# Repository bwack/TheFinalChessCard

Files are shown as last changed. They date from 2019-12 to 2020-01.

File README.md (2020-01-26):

# TheFinalChessCard Replica

TheFinalChessCard for C64/C128, replicated using SprintLayout. Here are the sprint and gerber files.

The scanned images are from the World of Jani blog article about this card. See also the forum64.de threads.
- http://blog.worldofjani.com/?p=3460
- https://www.forum64.de/index.php?thread/73757-the-final-chesscard/

## preview images from SprintLayout

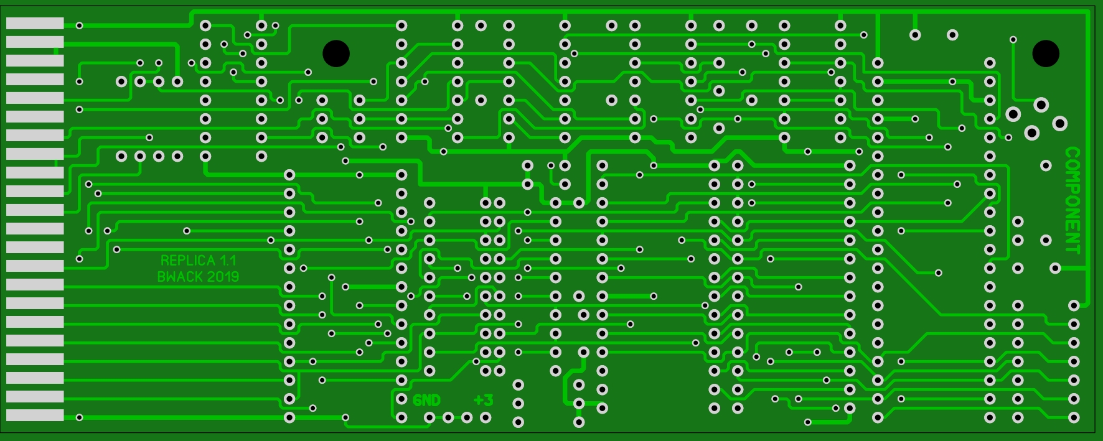
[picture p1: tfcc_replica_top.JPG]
replica top

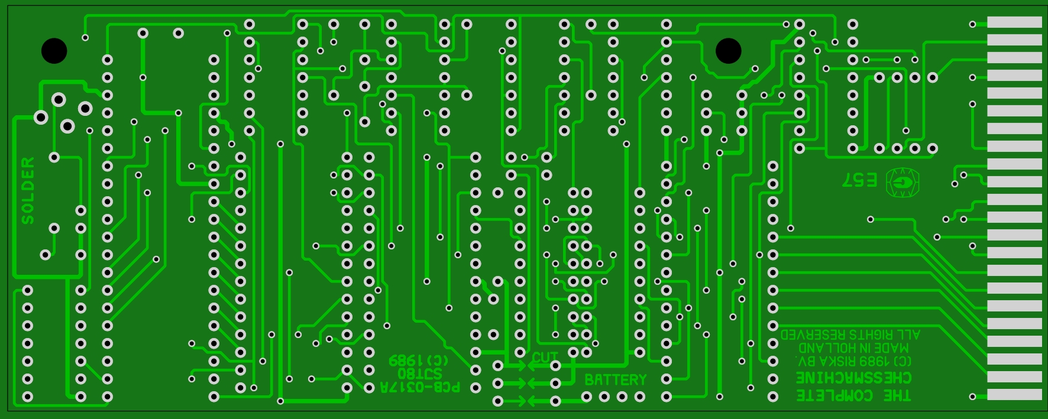
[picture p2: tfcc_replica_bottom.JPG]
replica bottom


# The Replica 1.0 prototype

The PCB Rev 1.0 has been [prototyped by Amon_RA on twitter](https://twitter.com/Amon_RA/status/1220659582181224448 "The tweets"). Thank you so much! Here are two images from his setup:

Image 1            |  Image 2
:-------------------------:|:-------------------------:
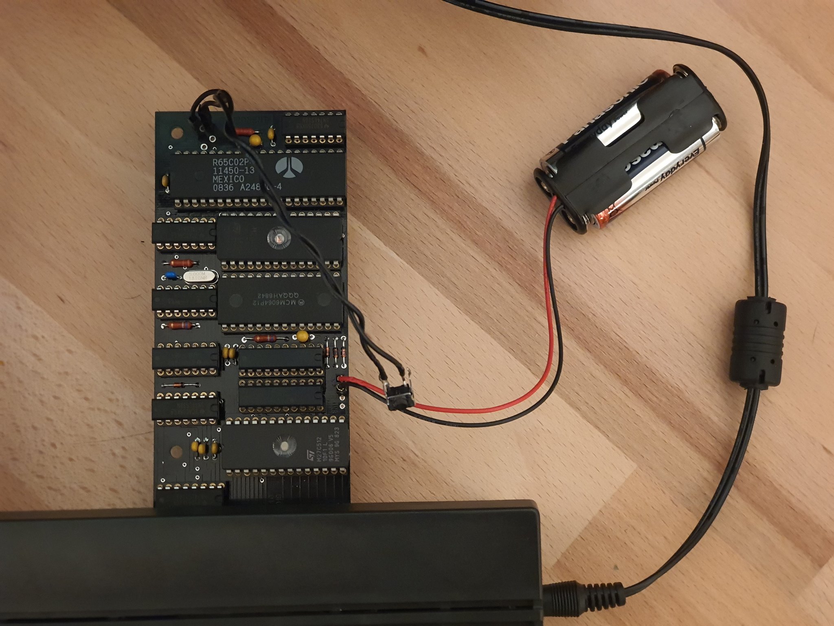
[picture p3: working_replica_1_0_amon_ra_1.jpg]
cart
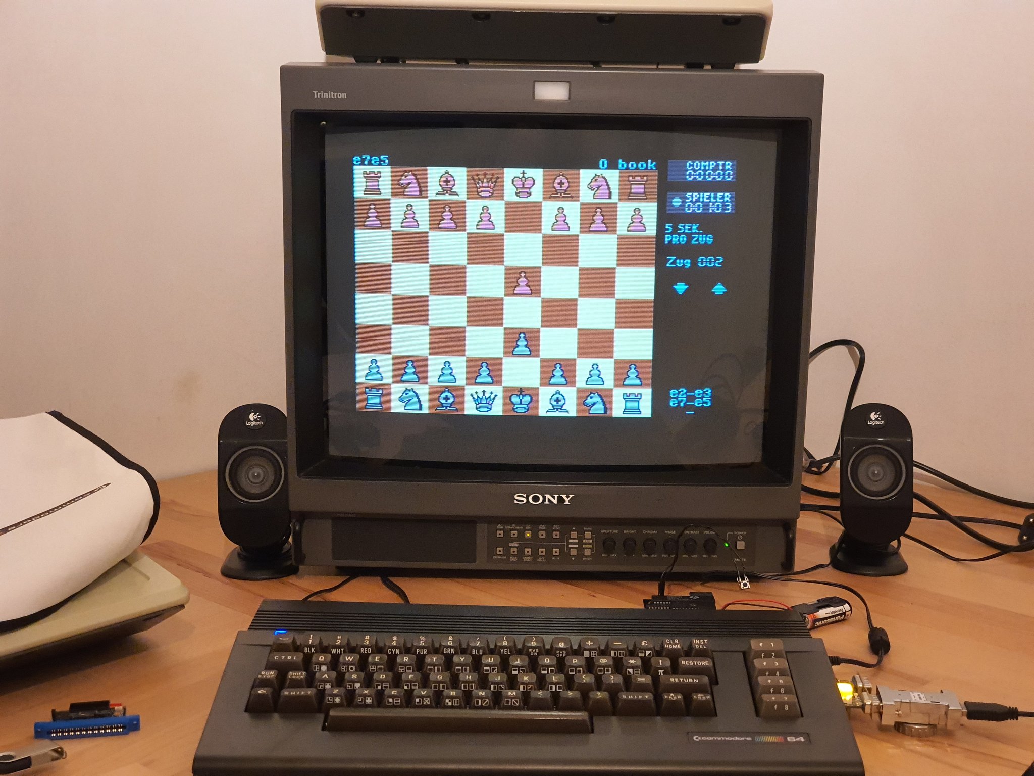
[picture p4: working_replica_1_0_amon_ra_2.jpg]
screen
  |  

The Rev 1.0 had a grounded READ pin near the top edge. To find it look at the 74LS32 closest to the CPU, pin 8. If you have Rev 1.0, cut this trace betwen pin8 and GND at top edge. This is fixed in Rev 1.1

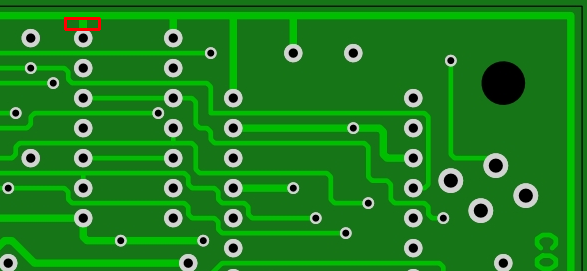
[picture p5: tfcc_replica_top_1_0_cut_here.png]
replica 1_0 cut here


I would also like to thank the work by lvr for the schematics draft he posted in [a forum64.de thread](https://www.forum64.de/index.php?thread/73757-the-final-chesscard/&postID=1139564#post1139564 "A draft of the schematics for TheFinalChessCart"). With this schematic I was able to match my gerbers against a netlist generated from his schematics, and in this way the error in Rev 1.0 was easy to spot. The draft was very close to the layout. Thanks also to [@thilographie_de](https://twitter.com/thilographie_de) for hunting the error with me.

# Links

After doing the C64 KU-motherboard and the videoseries, I still hadn't shown my viewers how I went from images to gerber files. This is where I got the motivation for doing this TFCC replica. I made two videos. The first video got linked on Jani's website and also ended up in an article about it on hackaday called [Reverse Engineer PCBs With SprintLayout](https://hackaday.com/2019/12/31/reverse-engineer-pcbs-with-sprintlayout/). :-)

first video (https://www.youtube.com/watch?v=g0nkLJ4YQ2c)

update video (https://www.youtube.com/watch?v=2UtY5fDaRgo)

## Change log

* 2020-01-25 Rev 1.1:
  * pin 8 "READ" on 74LS32 (near CPU) was grounded. Removed GND.
  * A trace stopped too early before a via. Still connected. Fixed.
* 2019-12-31 Rev 1.0: Touched up traces on a finer grid. 45degree bends.
* shown in video: traced up. quick 90 degree bends

# TheFinalChessCard KiCad (modified replica)

The replica above I'd like to be .. a replica. Some changes are desired.
In this KiCad version we have moved two ICs back onto the grid. They were just too close for IC sockets.
A zener diode was also too close to the same ICs. The crystal touched some metal. The power rails were thin.
I have solved the changes in this version.
The schematics were drafted by lvr as mentioned above regarding the PCB Rev 1.0.

Gerbers are available. Look under the KiCad folder.

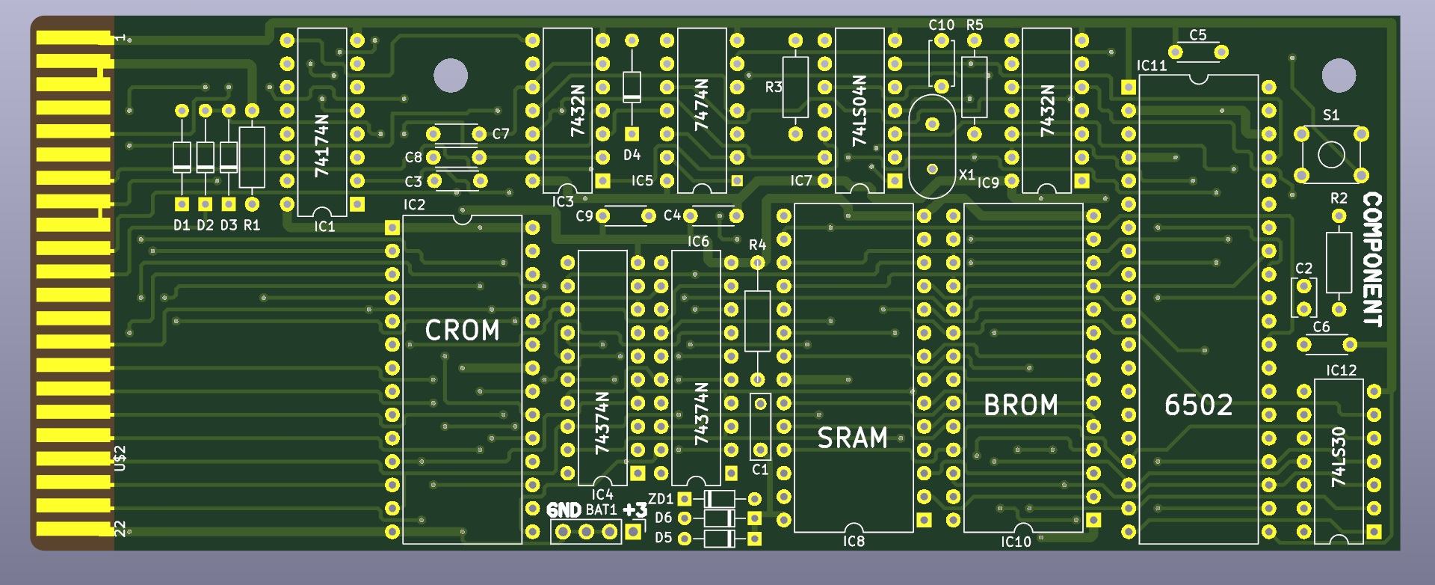
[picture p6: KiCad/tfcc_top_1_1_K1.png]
tfccmod pcb top

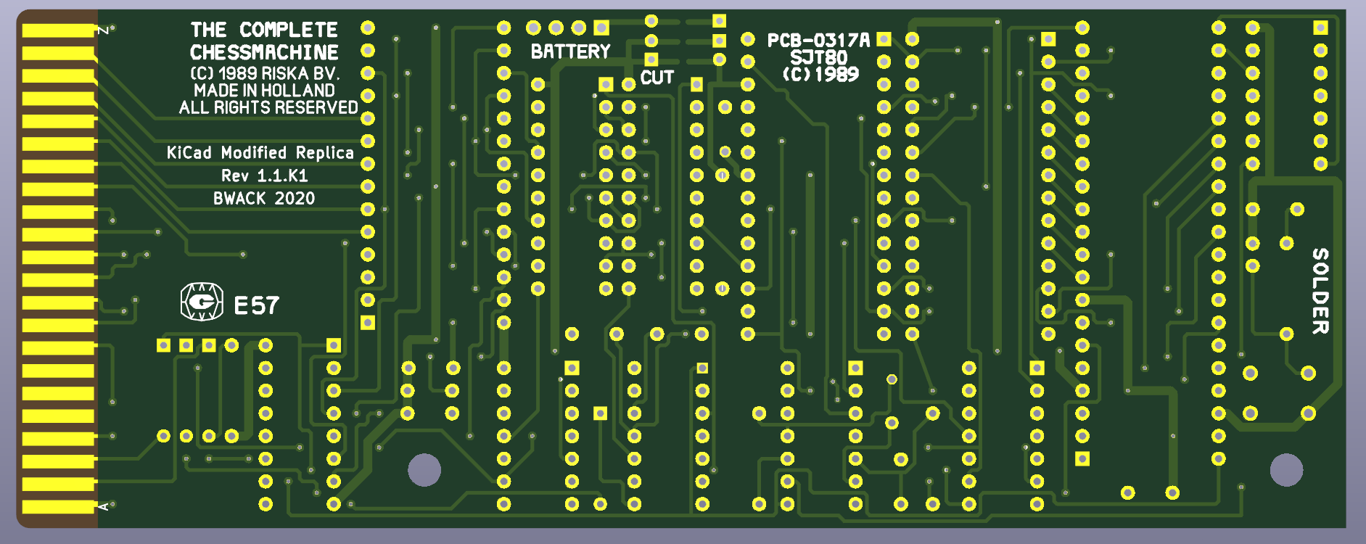
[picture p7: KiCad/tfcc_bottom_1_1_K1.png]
tfccmod pcb bottom


## Change log
The KiCad version branches off from the replica 1.1 board, hence why it is called 1.1.K1 where K is KiCad :)

Note that this version has never been prototype. Use at own risk if you decide to do so!

* 2020-01-26 Rev 1.1.K1:
  * Silkscreen artwork
  * Thicker power traces (0.63. -> 1mm)
  * Better space between two ICs. Moved some components to satisfy Cortyard errors.
  * New reset button. Standard 5x5mm push button.

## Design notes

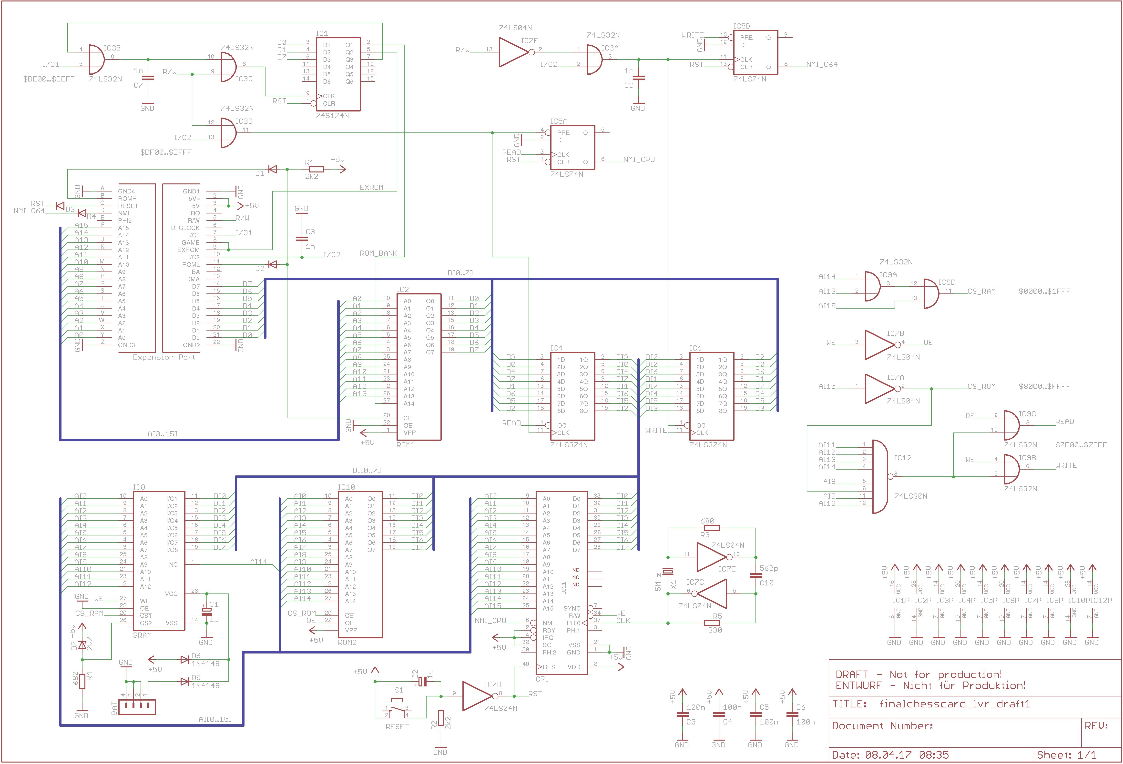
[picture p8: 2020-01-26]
KiCad/finalchesscard_lvr_draft1/finalchesscard_lvr_draft1.png

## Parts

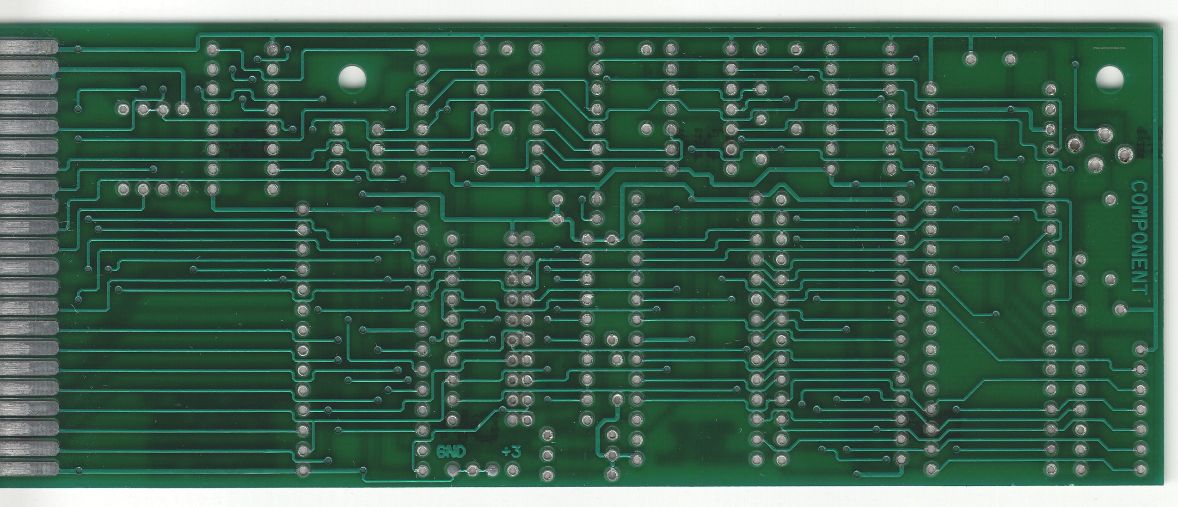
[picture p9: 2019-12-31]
TFCC_component_straight.jpg

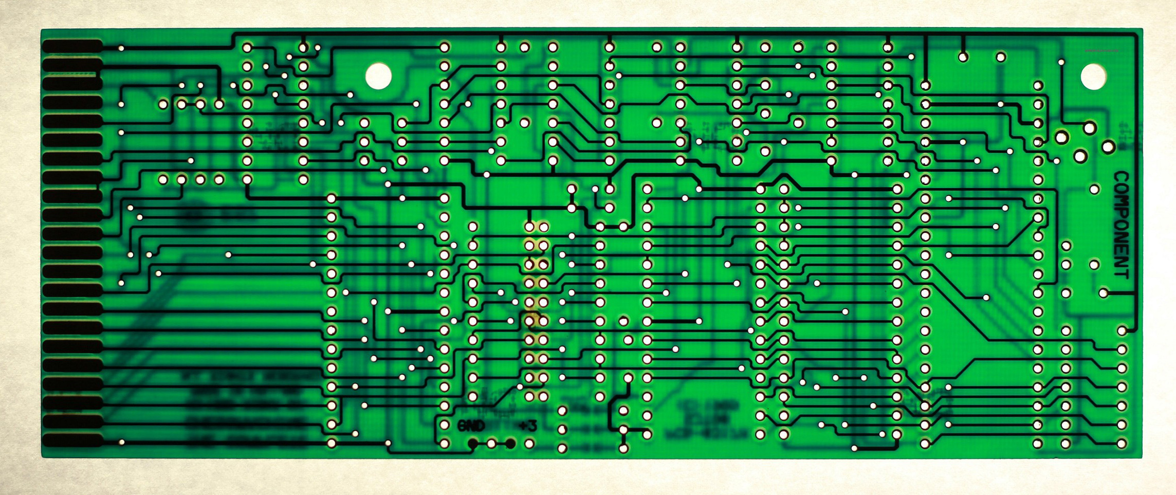
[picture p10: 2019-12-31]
TFCC_component_light_straight.jpg

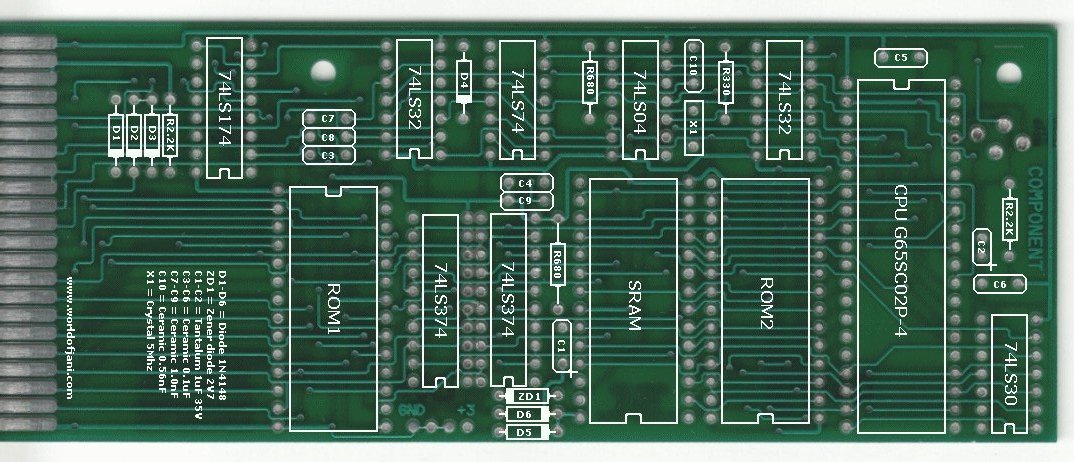
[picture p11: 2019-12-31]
TFCC_components_silk.jpg

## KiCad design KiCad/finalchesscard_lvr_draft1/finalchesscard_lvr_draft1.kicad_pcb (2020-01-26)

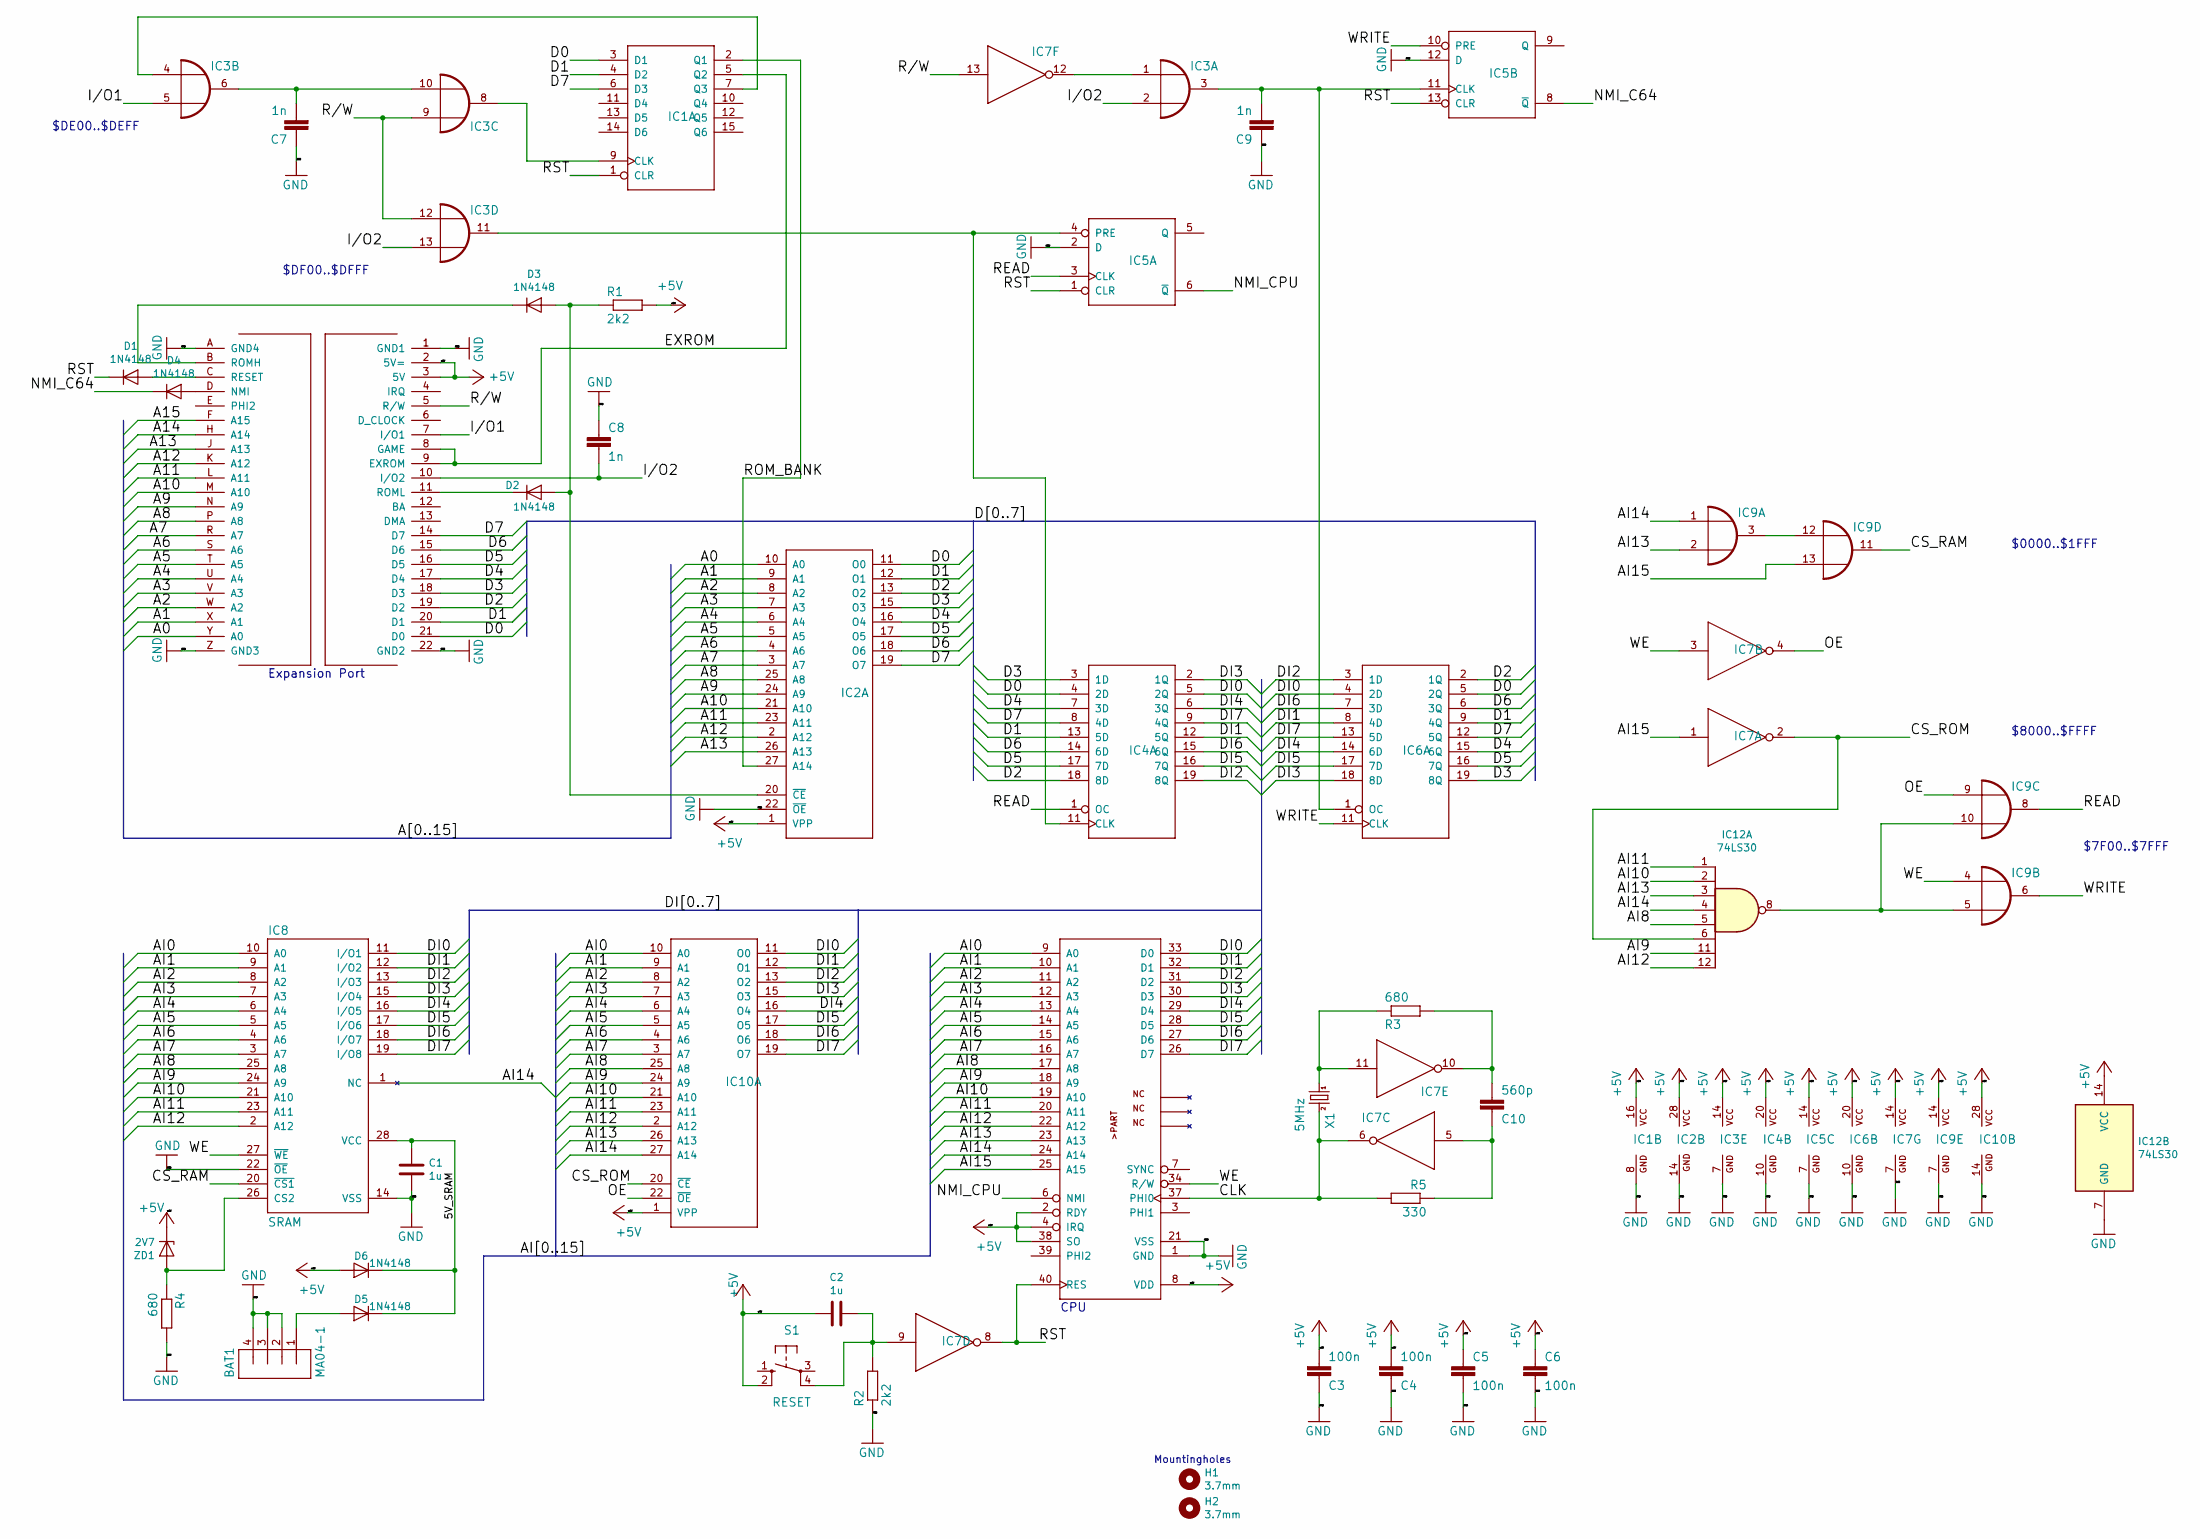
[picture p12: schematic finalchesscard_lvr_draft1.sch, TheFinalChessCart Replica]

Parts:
BAT1: MA04-1; PinHeader_1x04_P2.54mm_Vertical
C1: 1u; C_Rect_L7.0mm_W2.0mm_P5.00mm
C2: 1u; C_Rect_L4.0mm_W2.5mm_P2.50mm
C3, C4, C5, C6: 100n; C_Disc_D4.3mm_W1.9mm_P5.00mm
C7, C8, C9: 1n; C_Disc_D4.3mm_W1.9mm_P5.00mm
C10: 560p; C_Disc_D4.3mm_W1.9mm_P5.00mm
D1, D2, D3, D4: 1N4148; D_DO-34_SOD68_P10.16mm_Horizontal
D5, D6: 1N4148; D_DO-34_SOD68_P7.62mm_Horizontal
H1, H2: 3.7mm; MountingHole_3.7mm
IC1: 74174N; DIP-16_W7.62mm
IC2: ROM1; DIP-28_W15.24mm
IC3, IC9: 7432N; DIP-14_W7.62mm
IC4, IC6: 74374N; DIP-20_W7.62mm
IC5: 7474N; DIP-14_W7.62mm
IC7: 74LS04N; DIP-14_W7.62mm
IC8: SRAM; DIP-28_W15.24mm
IC10: ROM2; DIP-28_W15.24mm
IC11: 6502; DIP-40_W15.24mm
IC12: 74LS30; DIP-14_W7.62mm
R1, R2: 2k2; R_Axial_DIN0207_L6.3mm_D2.5mm_P10.16mm_Horizontal
R3: 680; R_Axial_DIN0207_L6.3mm_D2.5mm_P10.16mm_Horizontal
R4: 680; R_Axial_DIN0207_L6.3mm_D2.5mm_P15.24mm_Horizontal
R5: 330; R_Axial_DIN0207_L6.3mm_D2.5mm_P10.16mm_Horizontal
S1: RESET; SW_TH_Tactile_Omron_B3F-10xx
U$2: CARTRIDGE; C64_EXPANSION_PORT
X1: 5MHz; Crystal_HC49-U_Vertical
ZD1: 2V7; D_DO-34_SOD68_P7.62mm_Horizontal

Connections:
+5V: C2.2, C3.2, C4.2, C5.1, C6.1, D6.2 (A), IC1.16 (VCC), IC2.1 (VPP), IC2.28 (VCC), IC3.14 (VCC), IC4.20 (VCC), IC5.14 (VCC), IC6.20 (VCC), IC7.14 (VCC), IC9.14 (VCC), IC10.1 (VPP), IC10.28 (VCC), IC11.2 (RDY), IC11.4 (IRQ), IC11.8 (VDD), IC11.38 (SO), IC12.14 (VCC), R1.2, S1.2 (S1), U$2.2 (5V=), U$2.3 (5V), ZD1.1 (K)
/5V_SRAM: C1.1, D5.1 (K), D6.1 (K), IC8.28 (VCC)
/A0: IC2.10 (A0), U$2.Y (A0)
/A1: IC2.9 (A1), U$2.X (A1)
/A2: IC2.8 (A2), U$2.W (A2)
/A3: IC2.7 (A3), U$2.V (A3)
/A4: IC2.6 (A4), U$2.U (A4)
/A5: IC2.5 (A5), U$2.T (A5)
/A6: IC2.4 (A6), U$2.S (A6)
/A7: IC2.3 (A7), U$2.R (A7)
/A8: IC2.25 (A8), U$2.P (A8)
/A9: IC2.24 (A9), U$2.N (A9)
/A10: IC2.21 (A10), U$2.M (A10)
/A11: IC2.23 (A11), U$2.L (A11)
/A12: IC2.2 (A12), U$2.K (A12)
/A13: IC2.26 (A13), U$2.J (A13)
/A14: U$2.H (A14)
/A15: U$2.F (A15)
/AI0: IC8.10 (A0), IC10.10 (A0), IC11.9 (A0)
/AI1: IC8.9 (A1), IC10.9 (A1), IC11.10 (A1)
/AI2: IC8.8 (A2), IC10.8 (A2), IC11.11 (A2)
/AI3: IC8.7 (A3), IC10.7 (A3), IC11.12 (A3)
/AI4: IC8.6 (A4), IC10.6 (A4), IC11.13 (A4)
/AI5: IC8.5 (A5), IC10.5 (A5), IC11.14 (A5)
/AI6: IC8.4 (A6), IC10.4 (A6), IC11.15 (A6)
/AI7: IC8.3 (A7), IC10.3 (A7), IC11.16 (A7)
/AI8: IC8.25 (A8), IC10.25 (A8), IC11.17 (A8), IC12.5
/AI9: IC8.24 (A9), IC10.24 (A9), IC11.18 (A9), IC12.11
/AI10: IC8.21 (A10), IC10.21 (A10), IC11.19 (A10), IC12.2
/AI11: IC8.23 (A11), IC10.23 (A11), IC11.20 (A11), IC12.1
/AI12: IC8.2 (A12), IC10.2 (A12), IC11.22 (A12), IC12.12
/AI13: IC9.2 (I1), IC10.26 (A13), IC11.23 (A13), IC12.3
/AI14: IC8.1 (NC), IC9.1 (I0), IC10.27 (A14), IC11.24 (A14), IC12.4
/AI15: IC7.1 (I), IC9.13 (I1), IC11.25 (A15)
/CLK: IC7.6 (O), IC11.37 (PHI0), R5.2, X1.2
/CS_RAM: IC8.20 (~CS1), IC9.11 (O)
/CS_ROM: IC7.2 (O), IC10.20 (~CE), IC12.6
/D0: IC1.3 (D1), IC2.11 (O0), IC4.4 (2D), IC6.5 (2Q), U$2.21 (D0)
/D1: IC1.4 (D2), IC2.12 (O1), IC4.13 (5D), IC6.9 (4Q), U$2.20 (D1)
/D2: IC2.13 (O2), IC4.18 (8D), IC6.2 (1Q), U$2.19 (D2)
/D3: IC2.15 (O3), IC4.3 (1D), IC6.19 (8Q), U$2.18 (D3)
/D4: IC2.16 (O4), IC4.7 (3D), IC6.15 (6Q), U$2.17 (D4)
/D5: IC2.17 (O5), IC4.17 (7D), IC6.16 (7Q), U$2.16 (D5)
/D6: IC2.18 (O6), IC4.14 (6D), IC6.6 (3Q), U$2.15 (D6)
/D7: IC1.6 (D3), IC2.19 (O7), IC4.8 (4D), IC6.12 (5Q), U$2.14 (D7)
/DI0: IC4.5 (2Q), IC6.4 (2D), IC8.11 (I/O1), IC10.11 (O0), IC11.33 (D0)
/DI1: IC4.12 (5Q), IC6.8 (4D), IC8.12 (I/O2), IC10.12 (O1), IC11.32 (D1)
/DI2: IC4.19 (8Q), IC6.3 (1D), IC8.13 (I/O3), IC10.13 (O2), IC11.31 (D2)
/DI3: IC4.2 (1Q), IC6.18 (8D), IC8.15 (I/O4), IC10.15 (O3), IC11.30 (D3)
/DI4: IC4.6 (3Q), IC6.14 (6D), IC8.16 (I/O5), IC10.16 (O4), IC11.29 (D4)
/DI5: IC4.16 (7Q), IC6.17 (7D), IC8.17 (I/O6), IC10.17 (O5), IC11.28 (D5)
/DI6: IC4.15 (6Q), IC6.7 (3D), IC8.18 (I/O7), IC10.18 (O6), IC11.27 (D6)
/DI7: IC4.9 (4Q), IC6.13 (5D), IC8.19 (I/O8), IC10.19 (O7), IC11.26 (D7)
/EXROM: IC1.5 (Q2), U$2.8 (GAME), U$2.9 (EXROM)
/I/O1: IC3.5 (I1), U$2.7 (I/O1)
/I/O2: C8.2, IC3.2 (I1), IC3.13 (I1), U$2.10 (I/O2)
/NMI_C64: D4.1 (K), IC5.8 (~Q)
/NMI_CPU: IC5.6 (~Q), IC11.6 (NMI)
/OE: IC7.4 (O), IC9.9 (I0), IC10.22 (~OE)
/R/W: IC3.9 (I0), IC3.12 (I0), IC7.13 (I), U$2.5 (R/W)
/READ: IC4.1 (OC), IC5.3 (CLK), IC9.8 (O)
/ROM_BANK: IC1.2 (Q1), IC2.27 (A14)
/RST: D1.1 (K), IC1.1 (CLR), IC5.1 (CLR), IC5.13 (CLR), IC7.8 (O), IC11.40 (RES)
/WE: IC7.3 (I), IC8.27 (~WE), IC9.4 (I0), IC11.34 (R/W)
/WRITE: IC5.10 (PRE), IC6.11 (CLK), IC9.6 (O)
GND: BAT1.2, BAT1.3, BAT1.4, C1.2, C3.1, C4.1, C5.2, C6.2, C7.1, C8.1, C9.1, IC1.8 (GND), IC2.14 (GND), IC2.22 (~OE), IC3.7 (GND), IC4.10 (GND), IC5.2 (D), IC5.7 (GND), IC5.12 (D), IC6.10 (GND), IC7.7 (GND), IC8.14 (VSS), IC8.22 (~OE), IC9.7 (GND), IC10.14 (GND), IC11.1 (GND), IC11.21 (VSS), IC12.7 (GND), R2.1, R4.2, U$2.1 (GND1), U$2.22 (GND2), U$2.A (GND4), U$2.Z (GND3)
unnamed: BAT1.1, D5.2 (A)
unnamed: C2.1, IC7.9 (I), R2.2, S1.4 (P1)
unnamed: C7.2, IC3.6 (O), IC3.10 (I1)
unnamed: C9.2, IC3.3 (O), IC5.11 (CLK), IC6.1 (OC)
unnamed: C10.1, IC7.5 (I), R5.1
unnamed: C10.2, IC7.10 (O), R3.2
unnamed: D1.2 (A), U$2.C (RESET)
unnamed: D2.1 (K), U$2.11 (ROML)
unnamed: D2.2 (A), D3.2 (A), IC2.20 (~CE), R1.1
unnamed: D3.1 (K), U$2.B (ROMH)
unnamed: D4.2 (A), U$2.D (NMI)
unnamed: IC1.7 (Q3), IC3.4 (I0)
unnamed: IC1.9 (CLK), IC3.8 (O)
unnamed: IC3.1 (I0), IC7.12 (O)
unnamed: IC3.11 (O), IC4.11 (CLK), IC5.4 (PRE)
unnamed: IC7.11 (I), R3.1, X1.1
unnamed: IC8.26 (CS2), R4.1, ZD1.2 (A)
unnamed: IC9.3 (O), IC9.12 (I0)
unnamed: IC9.5 (I1), IC9.10 (I1), IC12.8

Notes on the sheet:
$0000..$1FFF
$8000..$FFFF
$DE00..$DEFF
$DF00..$DFFF
Expansion Port
$7F00..$7FFF
CPU
Mountingholes

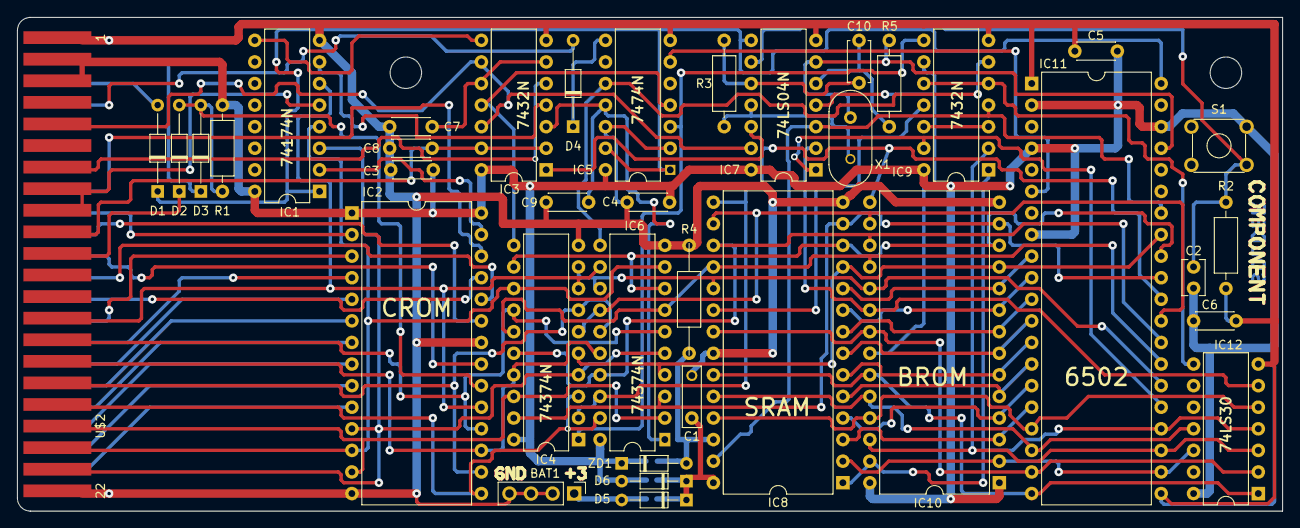
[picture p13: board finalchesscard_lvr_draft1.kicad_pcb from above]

Board: 2 copper layers, 148.9 x 58.1 mm, 40 parts (0 on the bottom side), 83 nets.

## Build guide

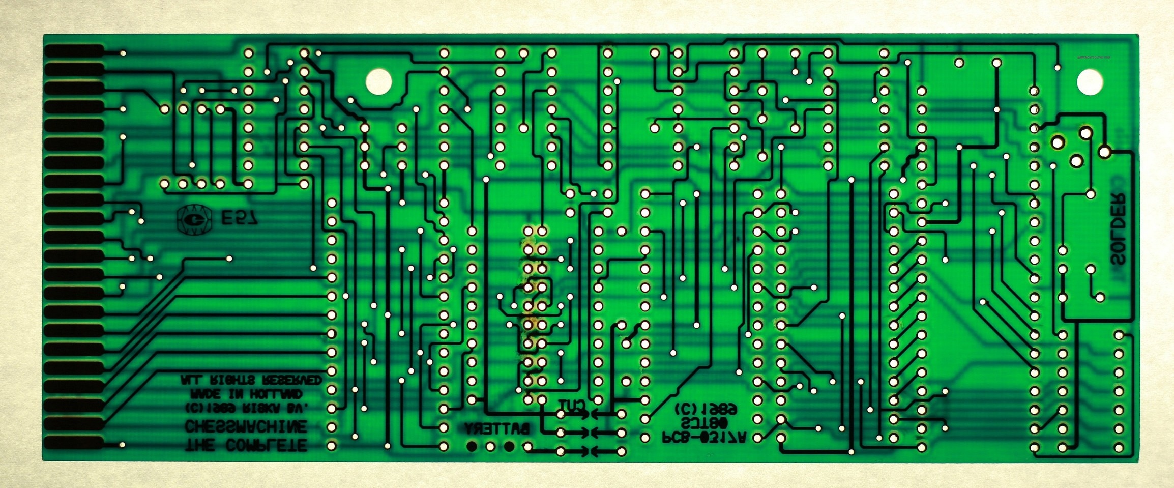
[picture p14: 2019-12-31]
TFCC_solder_light_flip.jpg

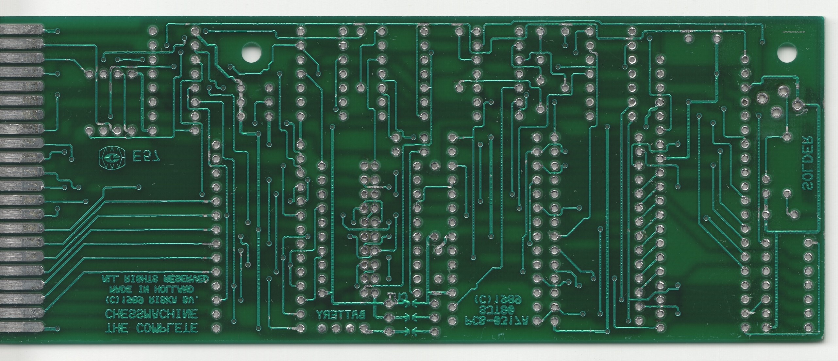
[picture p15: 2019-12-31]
TFCC_solder_flip.jpg

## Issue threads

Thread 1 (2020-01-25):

Two ICs are too close for sockets

bwack, 2020-01-25:
When adding IC sockets two ICs sits too close. There is room to fix move them.

bwack, 2020-01-26:
I'll add a KiCad version that makes changes to the replica. The replica shall be untouched.

Closed 2020-01-26.

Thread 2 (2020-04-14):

Missing indication of polarity on two capacitors

bwack, 2020-04-14:
The two caps needs a + on the silkscreen.

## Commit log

2019-12-31 added soldermask
    [tfcc.DRL, tfcc_copper_bottom.gbr, tfcc_copper_top.gbr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]
2020-01-25 Replica 1.1
    See readme
    [tfcc.DRL, tfcc_copper_bottom.gbr, tfcc_copper_top.gbr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]
2020-01-26 Added KiCad project modified
    [export_artwork.pcb.kicad_pcb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]
2020-01-26 Images of the modified board
